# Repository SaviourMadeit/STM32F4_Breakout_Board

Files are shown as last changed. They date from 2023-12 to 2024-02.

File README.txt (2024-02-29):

# STM32F405RGT6_Breakout_Board

This repository contains the design files, schematics, and documentation for the STM32F4 Breakout Board.
This breakout board is designed to simplify the development process by providing easy access to essential 
features of the STM32F4 microcontroller, including voltage regulation, communication protocols, debugging interfaces, and indicator LEDs.

## Features

- 3.3V Voltage Regulator: The breakout board includes a 3.3V voltage regulator to ensure a stable power supply for 
                              connected peripherals and the STM32F4 microcontroller.

- 3.3V Power Pin: Provides a convenient 3.3V power pin for external components or modules that require a regulated power supply.

- LED Indicator: An indicator LED for visual feedback or status indication during development.

- Communication Protocols:

  - SPI: Headers and connectors for Serial Peripheral Interface (SPI) communication.
  - UART: Interface for Universal Asynchronous Receiver-Transmitter (UART) communication.
  - I2C: Connectors for Inter-Integrated Circuit (I2C) communication.

- Serial Wire Debugger Pins: Dedicated pins for Serial Wire Debugging (SWD) to assist in code development and debugging processes.

## Contents

- Schematics: Contains the schematic, and footprint files detailing the board's layout and connections.
- Gerber_Files: Gerber files for PCB fabrication and Assembly.
- Documentation: Additional documentation, usage guides, and pinout details.
- Examples: Sample code examples demonstrating the use of different communication protocols with the breakout board.

## Usage

1. Hardware Setup: Connect the necessary peripherals or components to the designated headers and pins on the breakout board.
   
2. Power Supply: Ensure a stable power supply of max 5v is provided to the breakout board through the appropriate power input VIN pin.

3. Communication: Utilize the provided headers and connectors to establish communication using SPI, UART, or I2C protocols.

4. Debugging: Utilize the Serial Wire Debugger pins for development and debugging of code. Refer to the documentation for more details on debugging setup.

## Contributing

Contributions to enhance the breakout board design, improve documentation, or add new features are welcome. 
Please follow the guidelines outlined in the `CONTRIBUTING.md` file.

## License

This project is licensed under the [MIT License](LICENSE).

## Acknowledgments

Special thanks to the Phil's Lab,STM32F4 community and contributors for their support and resources that aided in the development of this breakout board.

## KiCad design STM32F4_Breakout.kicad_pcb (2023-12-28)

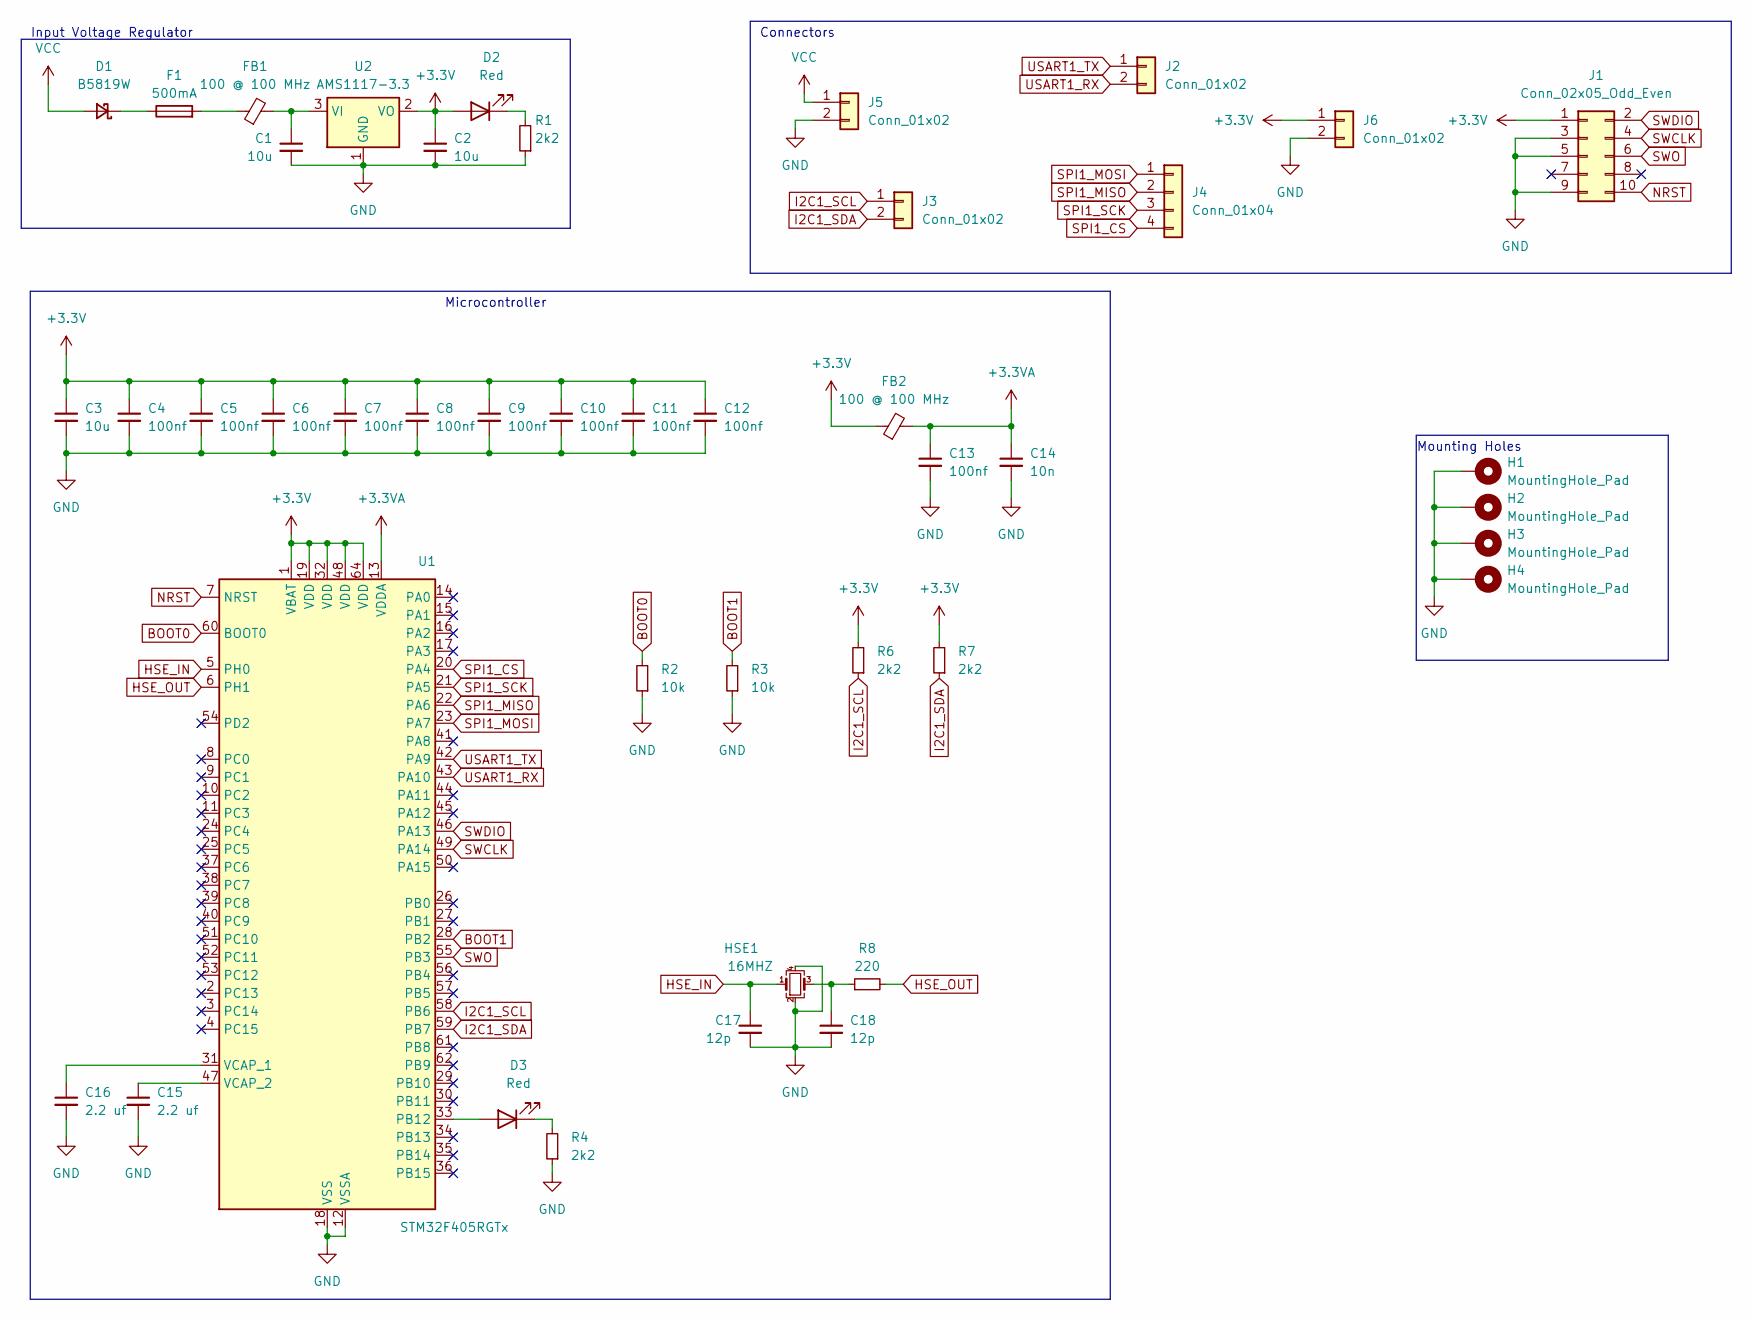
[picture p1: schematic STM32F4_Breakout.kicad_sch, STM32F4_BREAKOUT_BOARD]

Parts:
C1, C2: 10u; C_0805_2012Metric
C3: 10u; C_0603_1608Metric
C4, C5, C6, C7, C8, C9, C10, C11, C12, C13: 100nf; C_0402_1005Metric
C14: 10n; C_0402_1005Metric
C15, C16: 2.2 uf; C_0603_1608Metric
C17, C18: 12p; C_0402_1005Metric
D1: B5819W; D_SOD-123
D2, D3: Red; LED_0603_1608Metric
F1: 500mA; Fuse_0603_1608Metric
FB1, FB2: 100 @ 100 MHz; L_0805_2012Metric
H1, H2, H3, H4: MountingHole_Pad; MountingHole_4.3mm_M4_Pad_Via
HSE1: 16MHZ; Crystal_SMD_3225-4Pin_3.2x2.5mm
J1: Conn_02x05_Odd_Even; PinHeader_2x05_P2.54mm_Vertical_SMD
J2, J3, J5, J6: Conn_01x02; PinHeader_1x02_P2.54mm_Vertical
J4: Conn_01x04; PinHeader_1x04_P2.54mm_Vertical
R1, R4: 2k2; R_0603_1608Metric
R2, R3: 10k; R_0402_1005Metric
R6, R7: 2k2; R_0402_1005Metric
R8: 220; R_0402_1005Metric
U1: STM32F405RGTx; LQFP-64_10x10mm_P0.5mm
U2: AMS1117-3.3; SOT-223-3_TabPin2

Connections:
+3.3V: C2.1, C3.1, C4.1, C5.1, C6.1, C7.1, C8.1, C9.1, C10.1, C11.1, C12.1, D2.2 (A), FB2.1, J1.1, J6.1, R6.2, R7.2, U1.1 (VBAT), U1.19 (VDD), U1.32 (VDD), U1.48 (VDD), U1.64 (VDD), U2.2 (VO)
+3.3VA: C13.1, C14.1, FB2.2, U1.13 (VDDA)
BOOT0: R2.2, U1.60 (BOOT0)
BOOT1: R3.2, U1.28 (PB2)
GND: C1.2, C2.2, C3.2, C4.2, C5.2, C6.2, C7.2, C8.2, C9.2, C10.2, C11.2, C12.2, C13.2, C14.2, C15.2, C16.2, C17.2, C18.2, H1.1, H2.1, H3.1, H4.1, HSE1.2, HSE1.4, J1.3, J1.5, J1.9, J5.2, J6.2, R1.1, R2.1, R3.1, R4.1, U1.12 (VSSA), U1.18 (VSS), U1.63 (VSS), U2.1 (GND)
HSE_IN: C17.1, HSE1.1, U1.5 (PH0)
HSE_OUT: R8.2, U1.6 (PH1)
I2C1_SCL: J3.1, R6.1, U1.58 (PB6)
I2C1_SDA: J3.2, R7.1, U1.59 (PB7)
NRST: J1.10, U1.7 (NRST)
unnamed: C18.1, HSE1.3, R8.1
unnamed: D1.1 (K), F1.1
unnamed: D2.1 (K), R1.2
unnamed: D3.2 (A), U1.33 (PB12)
unnamed: D3.1 (K), R4.2
unnamed: F1.2, FB1.1
unnamed: C16.1, U1.31 (VCAP_1)
unnamed: C15.1, U1.47 (VCAP_2)
unnamed: C1.1, FB1.2, U2.3 (VI)
SPI1_CS: J4.4, U1.20 (PA4)
SPI1_MISO: J4.2, U1.22 (PA6)
SPI1_MOSI: J4.1, U1.23 (PA7)
SPI1_SCK: J4.3, U1.21 (PA5)
SWCLK: J1.4, U1.49 (PA14)
SWDIO: J1.2, U1.46 (PA13)
SWO: J1.6, U1.55 (PB3)
USART1_RX: J2.2, U1.43 (PA10)
USART1_TX: J2.1, U1.42 (PA9)
VCC: D1.2 (A), J5.1

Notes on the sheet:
Microcontroller
Mounting Holes
Input Voltage Regulator
Connectors

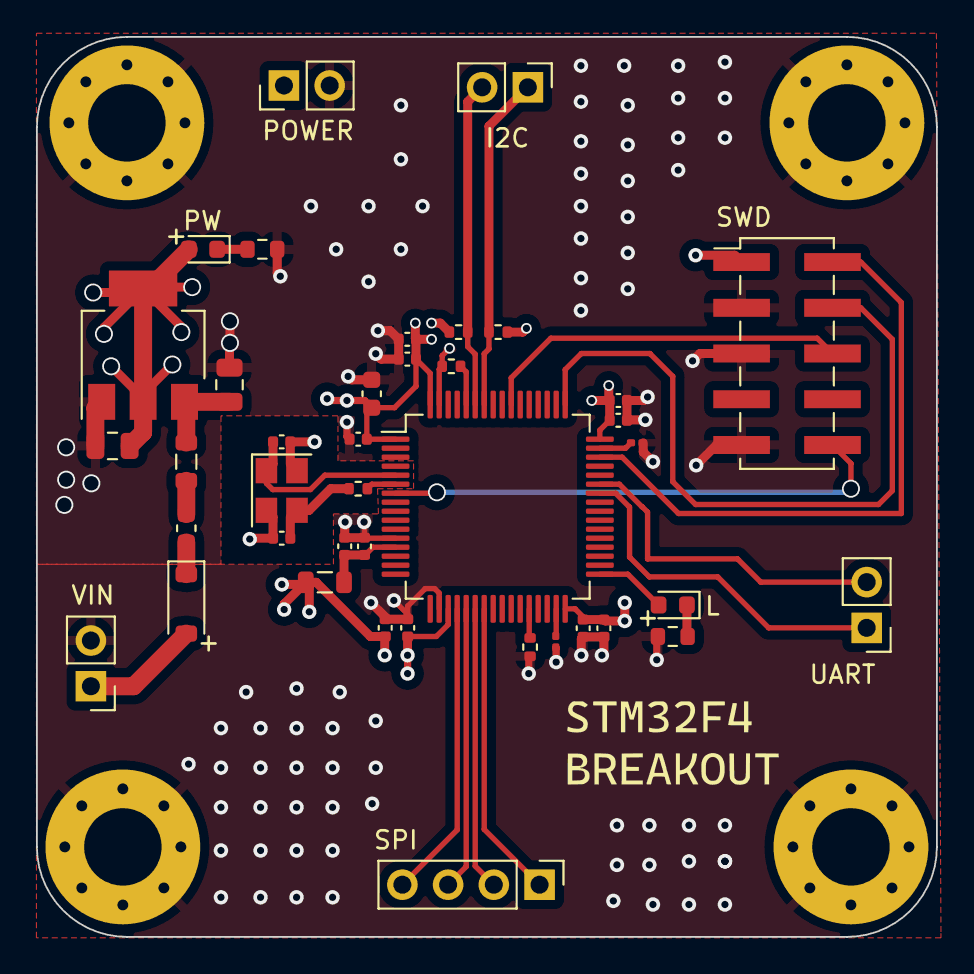
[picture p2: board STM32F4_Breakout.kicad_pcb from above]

Board: 4 copper layers, 50.0 x 50.0 mm, 44 parts (0 on the bottom side), 29 nets.
